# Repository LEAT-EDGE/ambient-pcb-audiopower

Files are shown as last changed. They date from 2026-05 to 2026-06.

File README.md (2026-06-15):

# Ambient audio capture and energy management daughterboard PCB

Audio capture and energy management daughterboard PCB for the [Ambient project](https://github.com/LEAT-EDGE/ambient).

<div style="display: flex; justify-content: center; gap: 20px;">
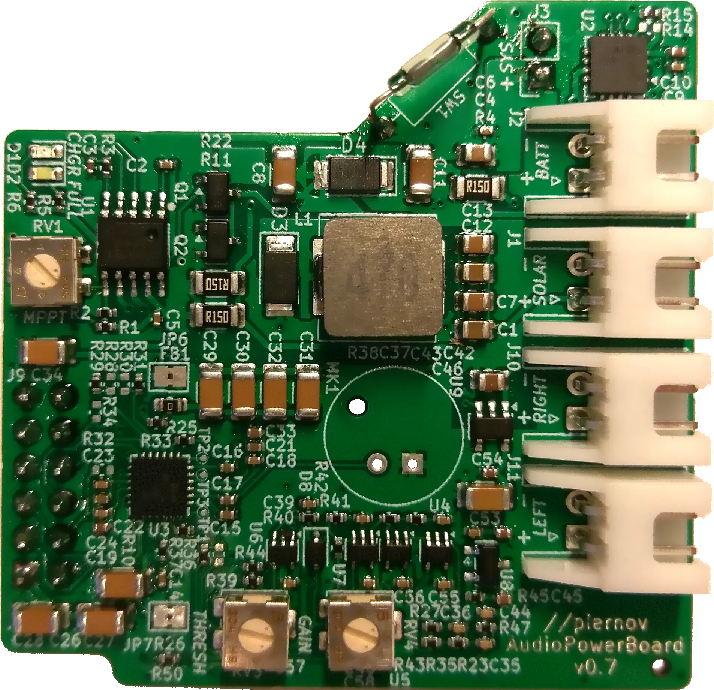
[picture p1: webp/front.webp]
Daughterboard front
    
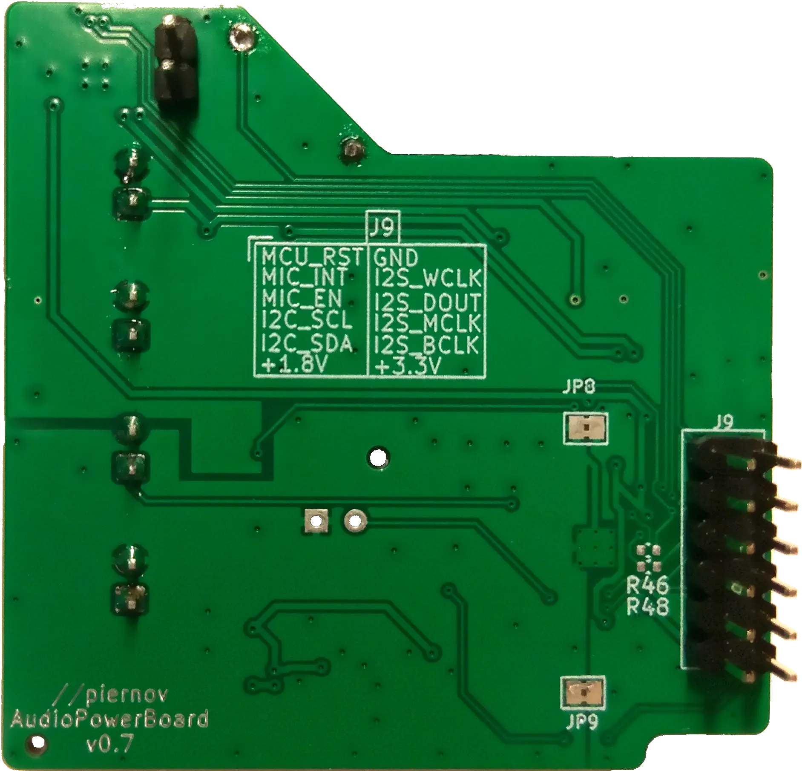
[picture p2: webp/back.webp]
Daughterboard back
    
</div>

## Main features

- Energy management:
  - Li-ion/LiPo charging circuit from photovoltaic cell with maximum power-point control (Consonance CN3791 controller),
  - solar and battery current and voltage monitoring (Texas Instrument INA3221 monitor),
- Audio capture:
  - analog-to-digital converter with microphone input amplification and digital filtering (Texas Instrument TLV320ADC3101),
  - analog audio wake-up circuit with high-pass filter and threshold detector.
- Magnetic reed switch for microcontroller reset

## Project structure
- `/` (repository root): KiCad project and libraries
- `pdf/`: Schematics generated from the KiCad project
- `png/`: Screenshots of the KiCad 3D render
- `production/`: Gerbers, BOM and placement files generated from the KiCad project (compatible with JLCPCB manufacturing and assembly)
- `webp/`: Pictures of the actual board

## Connectors and headers

### J1: SOLAR

Solar cell power input.

Solar cell voltage range: 4.6 V to 20 V.

| Pin | Net |
|---|---|
| **1** | `SOLAR+` |
| **2** | `GND` |

### J2: BATTERY

Li-ion or LiPo single-cell battery.

Minimum charging current rating: 800 mA.

Cell with built-in protection circuit required.

| Pin | Net |
|---|---|
| **1** | `BATT+` |
| **2** | `GND` |

### J3: SYS

Power output to the mainboard.

| Pin | Net |
|---|---|
| **1** | `SYS+` |
| **2** | `GND`  |

### J10: MIC_RIGHT

Unused in the Ambient variant.

Right condenser electret microphone input.

| Pin | Net |
|---|---|
| **1** | `MIC_RIGHT` |
| **2** | `GNDA` |

### J11: MIC_LEFT

Left condenser electret microphone input.

| Pin | Net |
|---|---|
| **1** | `MIC_LEFT` |
| **2** | `GNDA` |

### J9

Connects to the [mainboard PCB](https://github.com/LEAT-EDGE/ambient-pcb-dkaiot).

Pinout:

| Pin | Net | Pin | Net |
|---|---|---|---|
| **12** | `MCU_RESET` | **11** | `GND` |
| **10** | `EXT_MIC_IO_2` | **9**  | `SAI_FS` |
| **8**  | `EXT_MIC_IO_2` | **7**  | `SAI_SD` |
| **6**  | `I2C2_SCL` | **5**  | `SAI_MCLK` |
| **4**  | `I2C2_SDA` | **3**  | `SAI_SCK` |
| **2**  | `VDD_1V8` | **1**  | `V_PERIPH_3V` |

## Fabrication notes

### PCB

Standard 2-layer 1.6mm stackup:
- 2 layers (front/back),
- 1.6mm thickness (not mandatory),
- 1oz copper,
- FR-4 dielectric,
- HASL finish.

No special requirements, any solder mask and silkscreen color.

Gerbers, BOM and position files are provided in the `production/` directory but can be re-generated from the KiCad project using the Fabrication Toolkit plugin for JLCPCB.

### Assembly

Recommended automated assembly for top-side only.

Manual assembly for bottom side:
- J3 and J9 connectors (through-hole).

## Acknowledgment

This project has received funding from [Université Côte d'Azur](https://leat.univ-cotedazur.fr/) and [CERN](https://home.cern/).

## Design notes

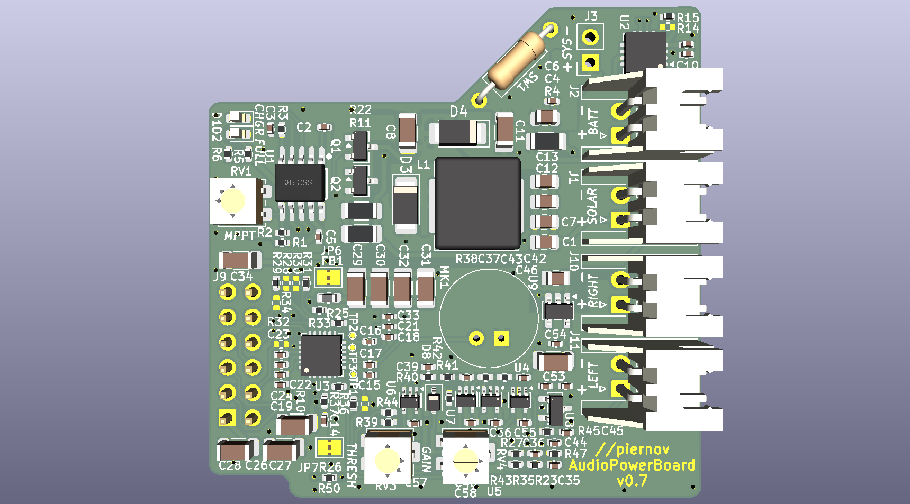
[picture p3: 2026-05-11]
png/AudioPowerBoard_front.png

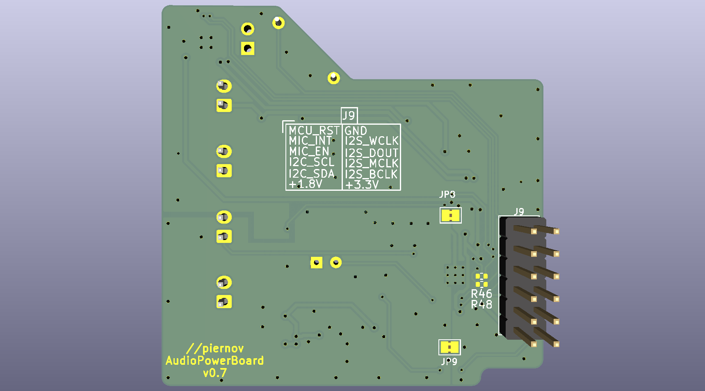
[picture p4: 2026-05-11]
png/AudioPowerBoard_back.png

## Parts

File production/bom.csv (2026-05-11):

Designator | Footprint | Quantity | Value | LCSC Part #
C1, C12, C13, C7 | 0805 | 4 | 22µF/25V | C45783
C10, C42, C45 | 0402 | 3 | 4.7µF/6.3V | C23733
C11, C8 | 1206 | 2 | 47µF/10V | C96123
C14, C24 | 0402 | 2 | 1uF/6.3V | C52923
C15, C16, C17, C21 | 0402 | 4 | 1uF | C52923
C18, C19, C23 | 0402 | 3 | 0.1uF | C1525
C2, C5 | 0402 | 2 | 100nF/25V | C307331
C22, C33, C54 | 0402 | 3 | 4.7uF/6.3V | C23733
C26, C27, C28, C29, C30, C31, C32, C34, C53 | 1206 | 9 | 100uF/6.3V | C15008
C3 | 0402 | 1 | 220nF/10V | C16772
C35, C36 | 0402 | 2 | 10nF | C15195
C37, C39, C40 | 0402 | 3 | 2.2uF | C12530
C4, C46 | 0805 | 2 | 4.7µF/10V | C1779
C43, C55, C56, C57, C58 | 0402 | 5 | 0.1µF/6.3V | C1525
C44 | 0402 | 1 | 10nF/6.3V | C15195
C6 | 0402 | 1 | 100nF | C1525
C9 | 0402 | 1 | 100nF/6.3V | C1525
D1 | 0603 | 1 | KT-0603R | C2286
D2 | 0603 | 1 | KT-0603W | C2290
D3, D4 | D_SOD-128 | 2 | PMEG6030ELPX | C2908821
D8 | D_SOD-323 | 1 | 1N5819WS | C191023
FB1 | 0603 | 1 | ~ | C21189
J1, J10, J11, J2 | JST_XH_S2B-XH-A-1_1x02_P2.50mm_Horizontal | 4 | Conn_01x02 | C163035
J9 | PinHeader_2x06_P2.54mm_Vertical | 1 | Conn_02x06_Odd_Even | C7501277
L1 | L_Sunlord_MWSA0804S | 1 | 47µH/3A | C2962889
Q1, Q2 | SOT-23 | 2 | AO3401A
R1 | 0402 | 1 | 33k | C25779
R10, R35, R39, R5, R6 | 0402 | 5 | 10k | C25744
R11, R22, R4 | 1206 | 3 | 0.150 | C2683383
R15, R29, R31 | 0402 | 3 | 47k | C25792
R2 | 0402 | 1 | 12k | C25752
R23 | 0402 | 1 | 11k | C25744
R25, R26, R45, R47 | 0402 | 4 | 2.2k | C25879
R27 | 0402 | 1 | 23k | C25768
R3 | 0402 | 1 | 120 | C25079
R33 | 0402 | 1 | 10 | C25077
R37, R50 | 0402 | 2 | 0 | C17168
R38, R41, R42 | 0402 | 3 | 4.7k | C25900
R40, R43, R44 | 0402 | 3 | 100k | C25741
RV1, RV3, RV4 | Potentiometer_Bourns_3314J_Vertical | 3 | 200k | C124643
U1 | SSOP-10_L4.9-W3.9-P1.00-LS6.0-BL | 1 | CN3791 | C154992
U2 | Texas_RGV0016A_VQFN-16-1EP_4x4mm_P0.65mm_EP2.1x2.1mm | 1 | INA3221 | C181255
U3 | VQFN-24-1EP_4x4mm_P0.5mm_EP2.5x2.5mm_ThermalVias_drill0.3 | 1 | TLV320ADC3101 | C162409
U4 | SOT-353_SC-70-5 | 1 | OPA379AIDCK | C576302
U5, U7 | SOT-353_SC-70-5 | 2 | OPA391DCKR | C2871876
U6 | SOT-353_SC-70-5 | 1 | TLV7031DCK | C2863637
U8 | SOT-23 | 1 | ISL21080CIH315Z-TK | C128623
U9 | TSOT-23-5 | 1 | RT9080-30GJ5 | C965900

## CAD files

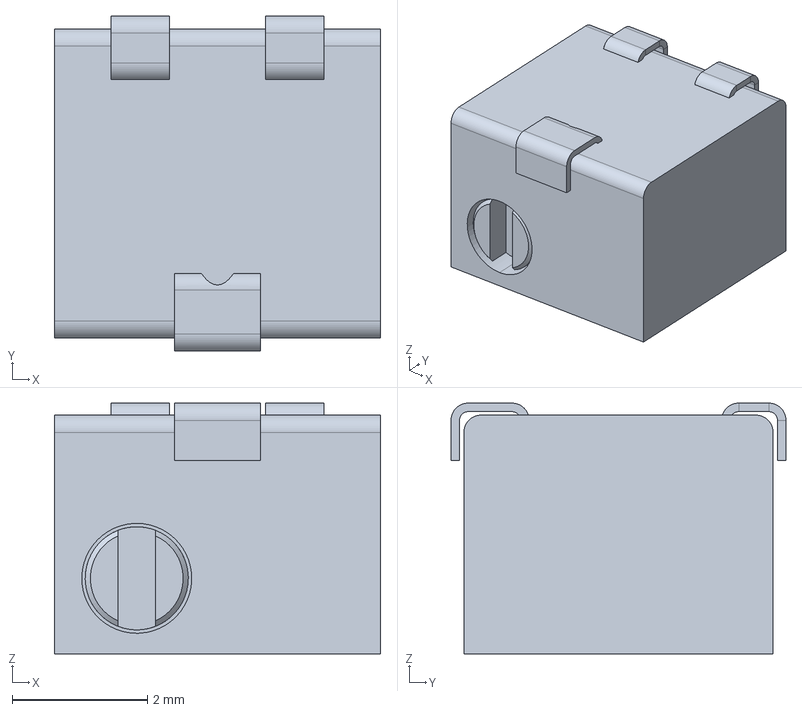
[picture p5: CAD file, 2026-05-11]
3224J.stp
4.83 x 4.95 x 3.71 mm

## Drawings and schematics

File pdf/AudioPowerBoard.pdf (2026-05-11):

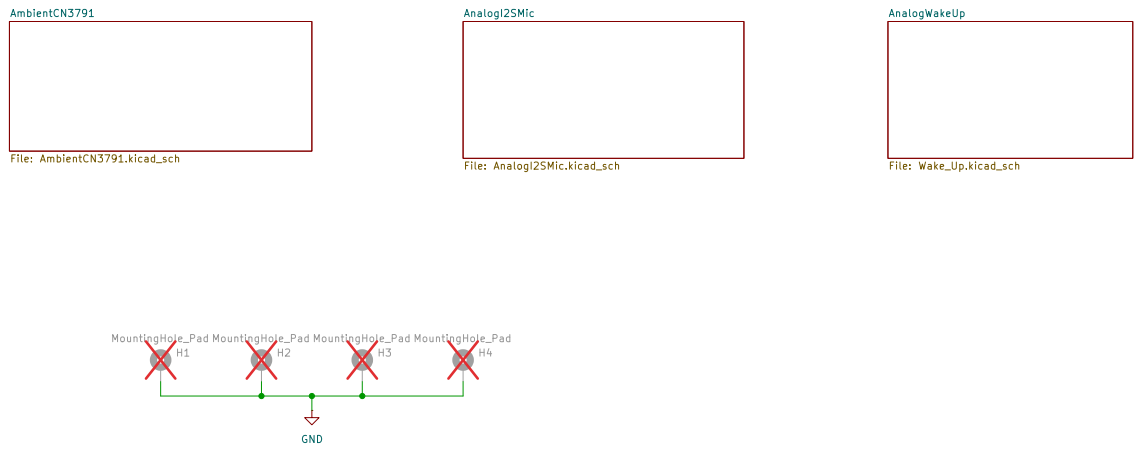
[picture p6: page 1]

Size: A4 | Rev: v0.7
KiCad E.D.A. 10.0.2 | Id: 1/4

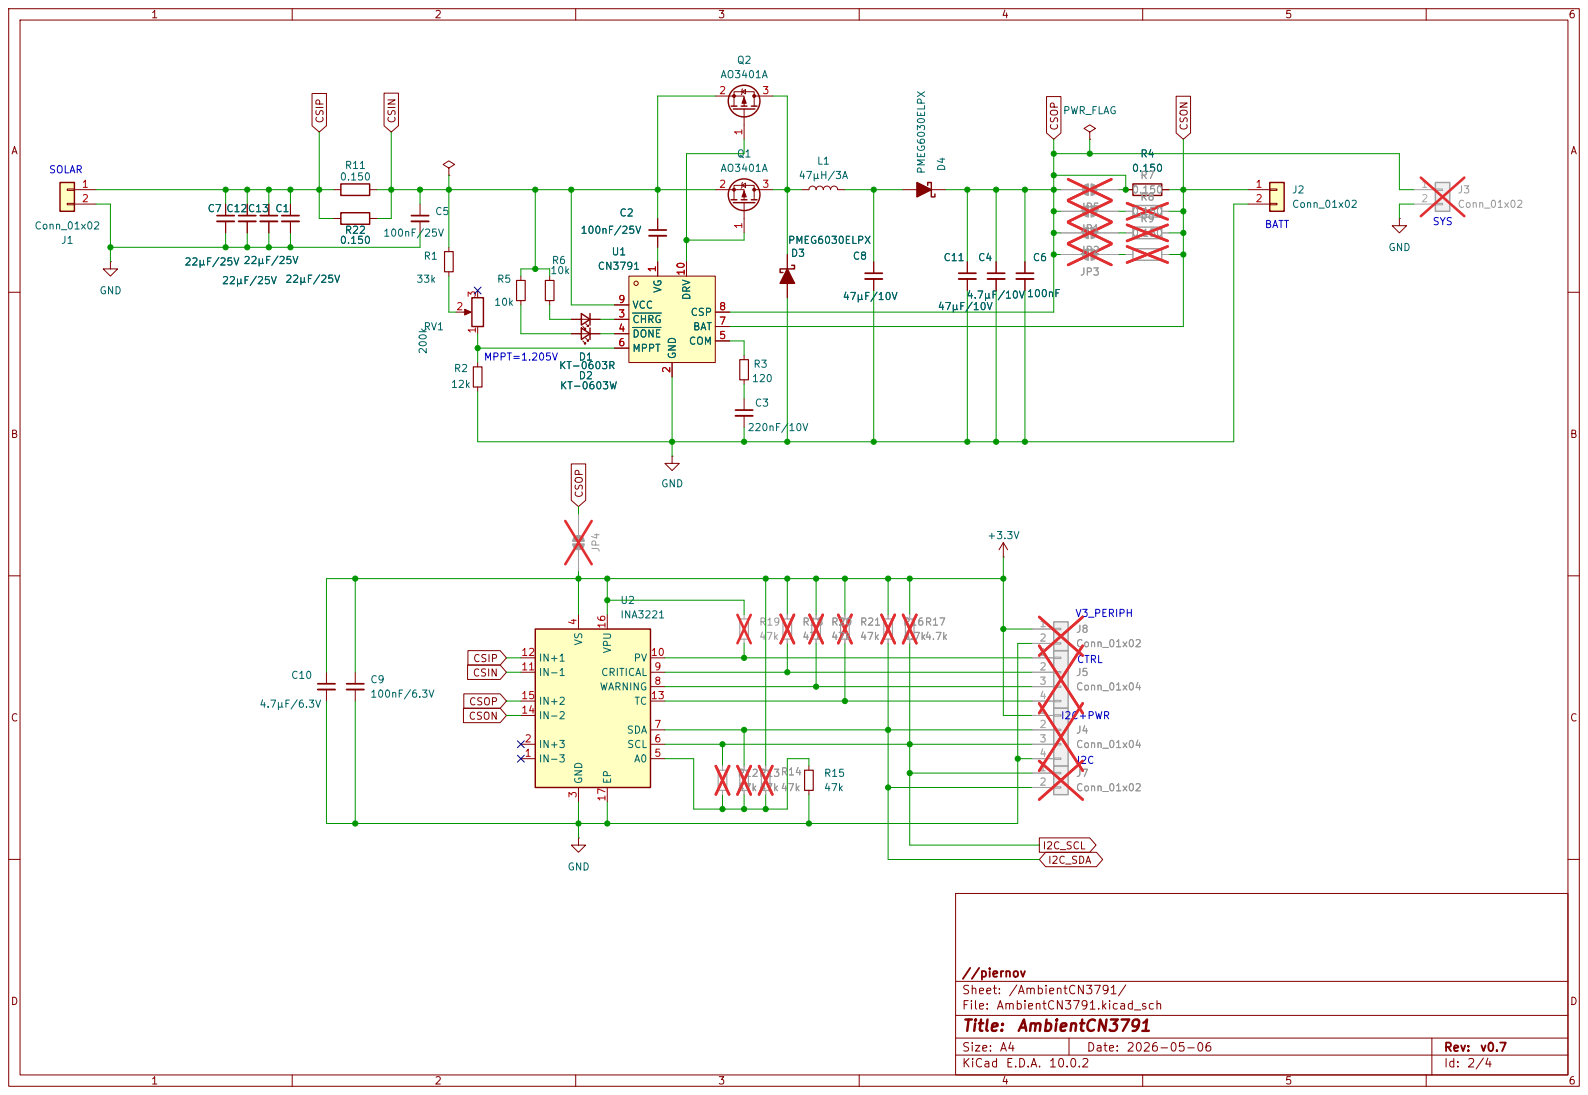
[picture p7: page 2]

2 CHRG 3 DONE 4 COM 5 MPPT 6 BAT 7 CSP VCC 8

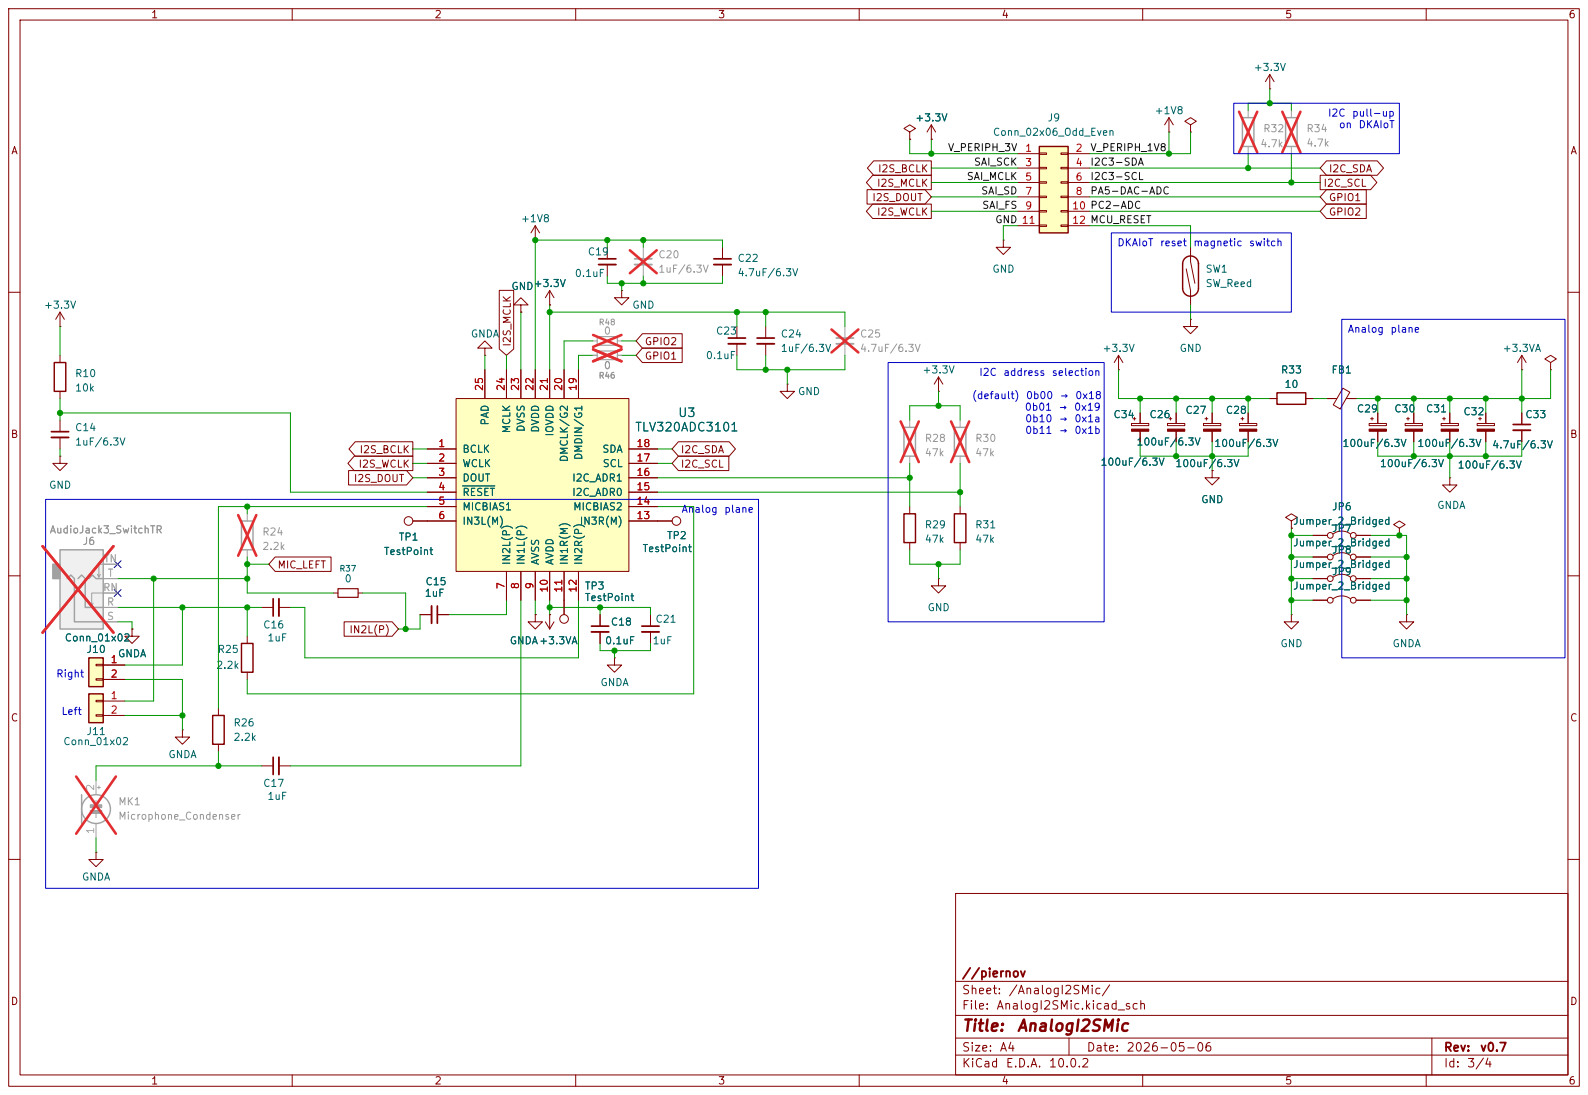
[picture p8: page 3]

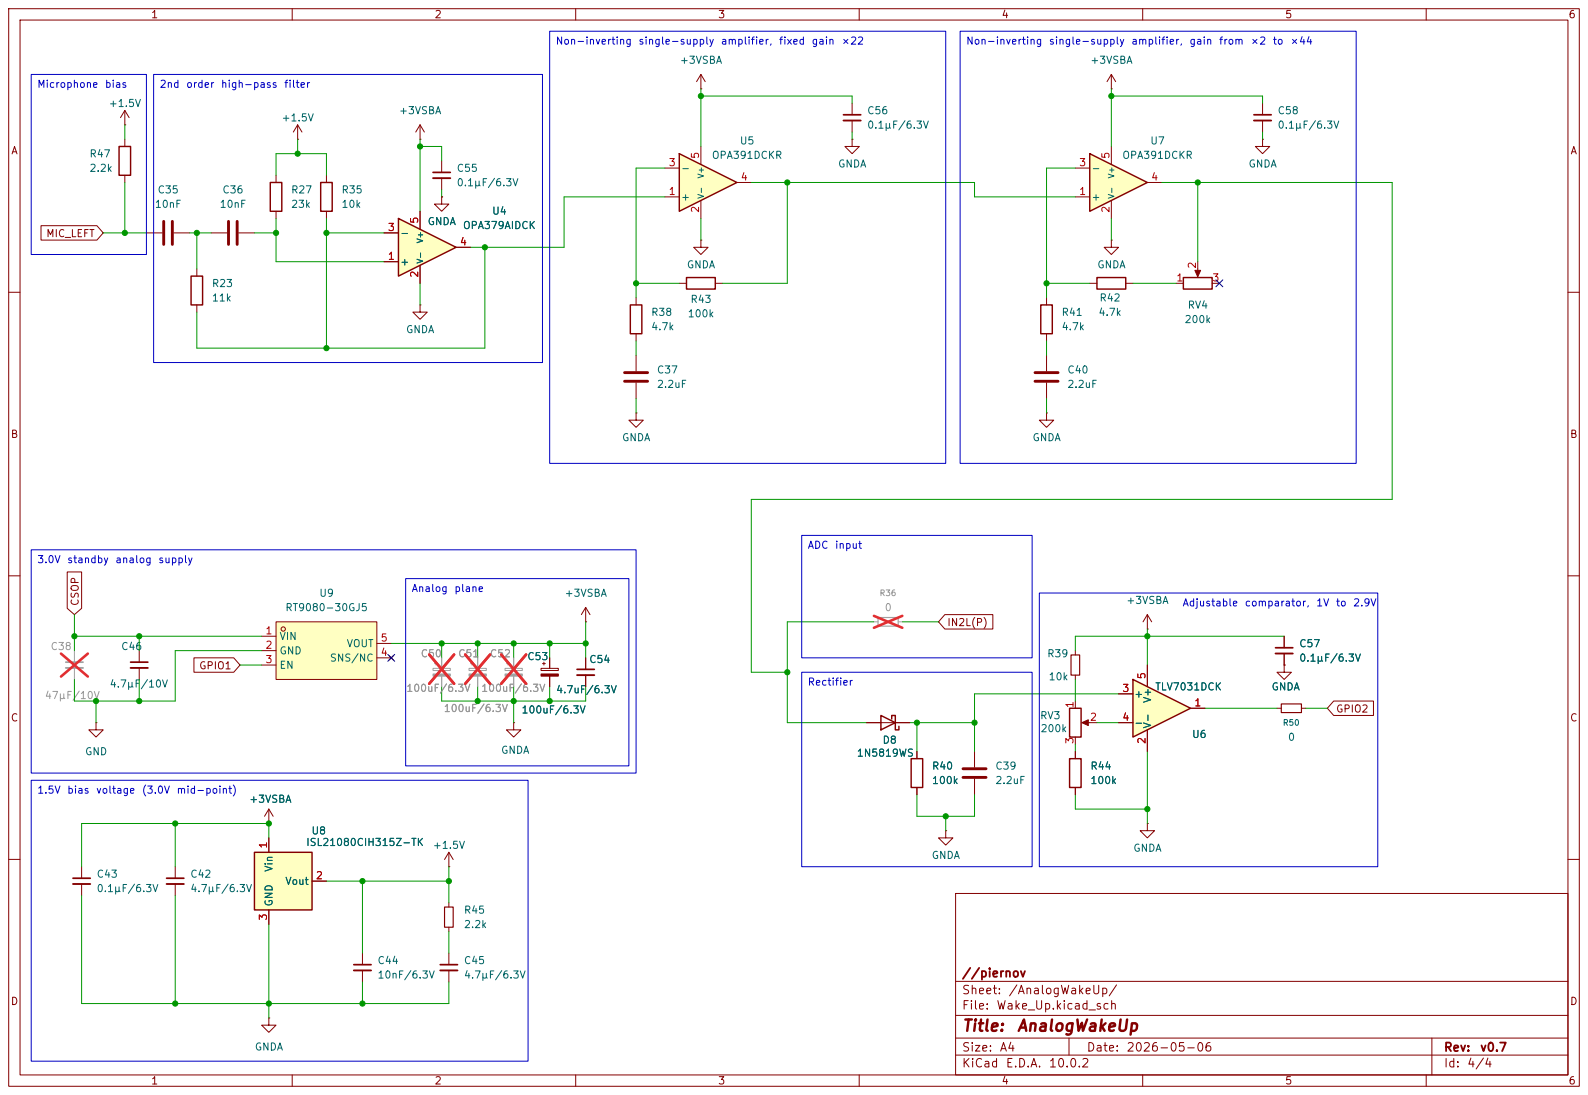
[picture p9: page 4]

Analog plane 3.0V standby analog supply

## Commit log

2023-02-20 Initial import
    [AnalogI2SMic.kicad_pcb, AnalogI2SMic.kicad_sch]
2023-02-21 AnalogI2SMic v0.1
    [AnalogI2SMic-B_Cu.gbl, AnalogI2SMic-B_Mask.gbs, AnalogI2SMic-B_Paste.gbp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]
2023-03-05 Connect RESET to 3.3V instead of 1.8V (closes #1)
    [AnalogI2SMic-B_Cu.gbl, AnalogI2SMic-B_Mask.gbs, AnalogI2SMic-B_Paste.gbp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]
2024-05-17 RT9073A LDO instead of AMS1117 and route GPIO1/GPIO2 to J3 instead of redundant power
    [AnalogI2SMic-B_Cu.gbl, AnalogI2SMic-B_Mask.gbs, AnalogI2SMic-B_Paste.gbp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]
2024-06-06 Fix for JLCPCB assembly
    [AnalogI2SMic-B_Cu.gbl, AnalogI2SMic-B_Mask.gbs, AnalogI2SMic-B_Paste.gbp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]
2024-09-10 Some cleanup in schematics
    [AnalogI2SMic.kicad_sch]
2024-09-19 Some changes for DKAIoT
    [AnalogI2SMic.kicad_sch]
2024-09-19 More changes for DKAIoT
    [AnalogI2SMic.kicad_pcb, AnalogI2SMic.kicad_sch]
2024-09-20 Modifications for DKAIoT
    [AnalogI2SMic-B_Cu.gbl, AnalogI2SMic-B_Mask.gbs, AnalogI2SMic-B_Paste.gbp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]
2024-10-21 Add bulk cap 330µF VDD/VDDA + add 0ohm resistor to bridge jack ring to GPIO2
    [AnalogI2SMic-B_Cu.gbl, AnalogI2SMic-B_Mask.gbs, AnalogI2SMic-B_Paste.gbp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]
2024-10-30 Change JLCPCB cap reference
    [AnalogI2SMic.kicad_pcb, AnalogI2SMic.kicad_sch, bom.csv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]
2024-11-19 Change value of bulk caps to 470µF in schematics according to JLCPCB parts selection
    [AnalogI2SMic.kicad_pcb, AnalogI2SMic.kicad_sch, bom.csv]
2024-11-22 AmbientCN3791 v0.1
    [AmbientCN3791.kicad_pcb, AmbientCN3791.kicad_sch, bom.csv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]
2024-11-28 v0.5: replace 2×470µF Tant with 7×100µF MLCC for supply and cost reduction
    [AnalogI2SMic.kicad_pcb, AnalogI2SMic.kicad_sch, bom.csv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]
2026-05-11 Add pdf/
    [AmbientCN3791.kicad_sch, AnalogI2SMic.kicad_sch, AudioPowerBoard.kicad_sch]
2026-05-11 Add production/
    [bom.csv, designators.csv, positions.csv]
2026-05-11 Schematics page name
    [AmbientCN3791.kicad_sch, AnalogI2SMic.kicad_sch]
2026-05-11 v0.2: fix SCL/SDA inversion for INA3221 + fix C8 silkscreen overlap + KiCad 9.0 update
    [AmbientCN3791.kicad_sch, AnalogI2SMic.kicad_sch, AudioPowerBoard.kicad_pcb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]
2026-05-11 v0.2: change diode reference and location for lower leakage + add extra decoupling cap on +3V3 + change potentiometer reference (equivalent) for JLCPCB supply constraint
    [AmbientCN3791.kicad_sch, AnalogI2SMic.kicad_sch, AudioPowerBoard.kicad_pcb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]
2026-05-11 v0.3: replace PMEG40T30EPX with PMEG6030EP,115 for supply constraint
    [AmbientCN3791.kicad_sch, AnalogI2SMic.kicad_sch, AudioPowerBoard.kicad_pcb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]
2026-05-11 v0.4: Omar Titouhi 08/10/25
    [AmbientCN3791.kicad_sch, AnalogI2SMic.kicad_sch, AudioPowerBoard.kicad_pcb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]
2026-05-11 WIP: 0.5
    [AmbientCN3791.kicad_sch, AnalogI2SMic.kicad_sch, AudioPowerBoard.kicad_sch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]
2026-05-11 v0.5: add jumper to select between U6 or U7 output for GPIO2
    [AudioPowerBoard.kicad_pcb, Wake_Up.kicad_sch, bom.csv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]
2026-05-11 Fix opamp supply polarity + KiCad 10 upgrade
    [AmbientCN3791.kicad_sch, AnalogI2SMic.kicad_sch, AudioPowerBoard.kicad_pcb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]
2026-05-11 v0.6: improve analog trigger circuit
    Remove monostable multivibrator (not needed, transition from low to high
    at comparator output is enough)
    Replace opamp in comparator circuit by actual comparator (saturated
    opamp draws far too much current)
    Add a second amplifier with fixed gain
    [AmbientCN3791.kicad_sch, AnalogI2SMic.kicad_sch, AudioPowerBoard.kicad_pcb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]
2026-05-11 v0.7: reed switch footprint for MCU reset
    [AmbientCN3791.kicad_sch, AnalogI2SMic.kicad_sch, AudioPowerBoard.kicad_pcb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]
